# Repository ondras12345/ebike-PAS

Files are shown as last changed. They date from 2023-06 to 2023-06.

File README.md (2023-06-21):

# e-bike PAS signal generator
Eunorau Sin-wave LD-FXK-038 e-bike controller is often used on electric kick
scooters, but those don't have pedals, so you cannot make use of the pedal
assist (PAS) feature. This simple device generates a valid pedalling signal to
achieve cruise control-like functionality.

## Usage
Hold the start button for at least 2 seconds to enable PAS. Start braking to
turn it off.

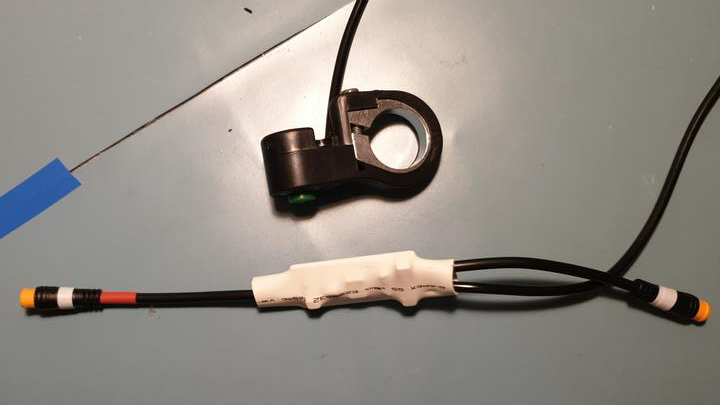
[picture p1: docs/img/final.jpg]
PCBA with connectors attached, wrapped in heatshrink

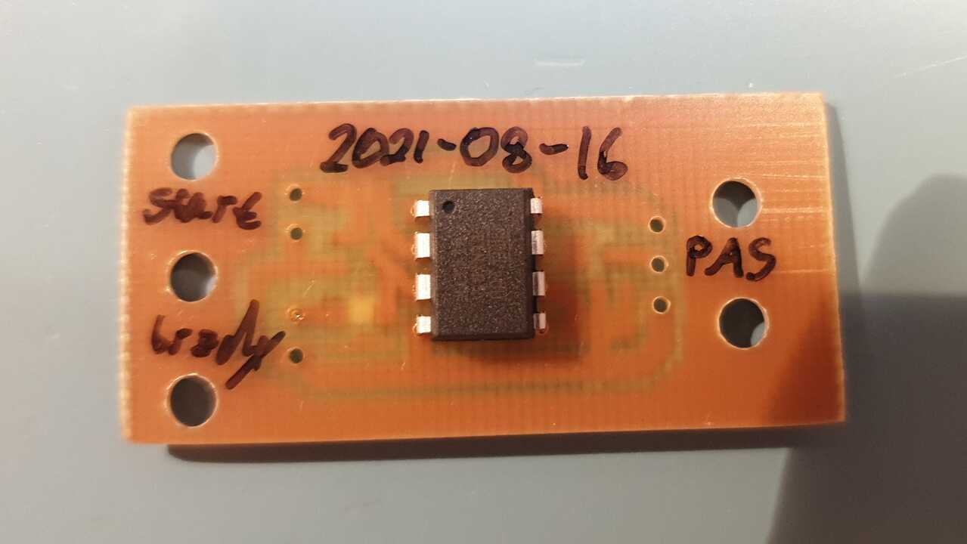
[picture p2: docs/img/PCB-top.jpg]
Top side of the PCBA

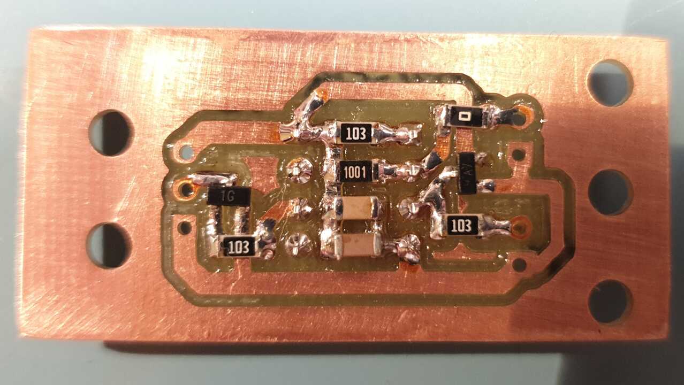
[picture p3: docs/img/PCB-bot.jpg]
Bottom side of the PCBA


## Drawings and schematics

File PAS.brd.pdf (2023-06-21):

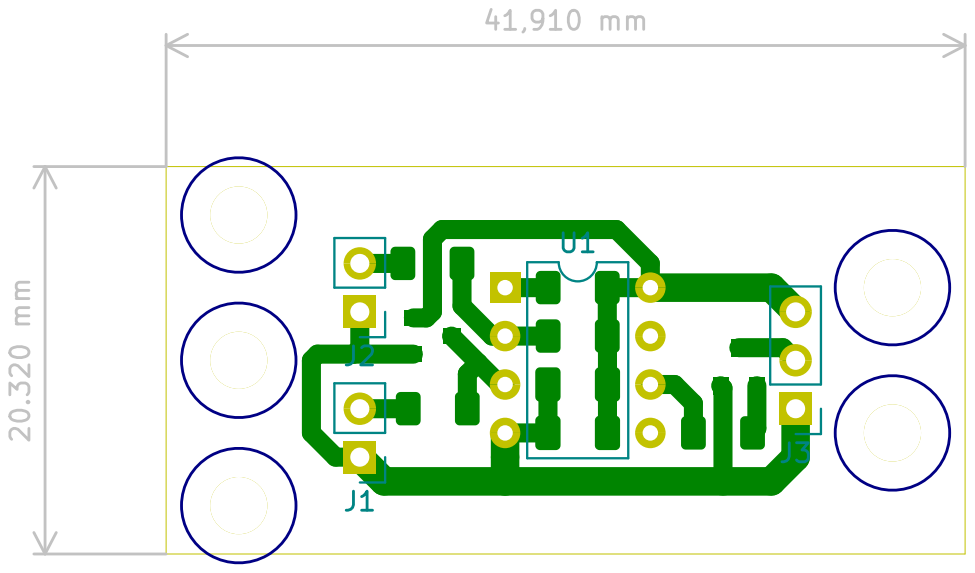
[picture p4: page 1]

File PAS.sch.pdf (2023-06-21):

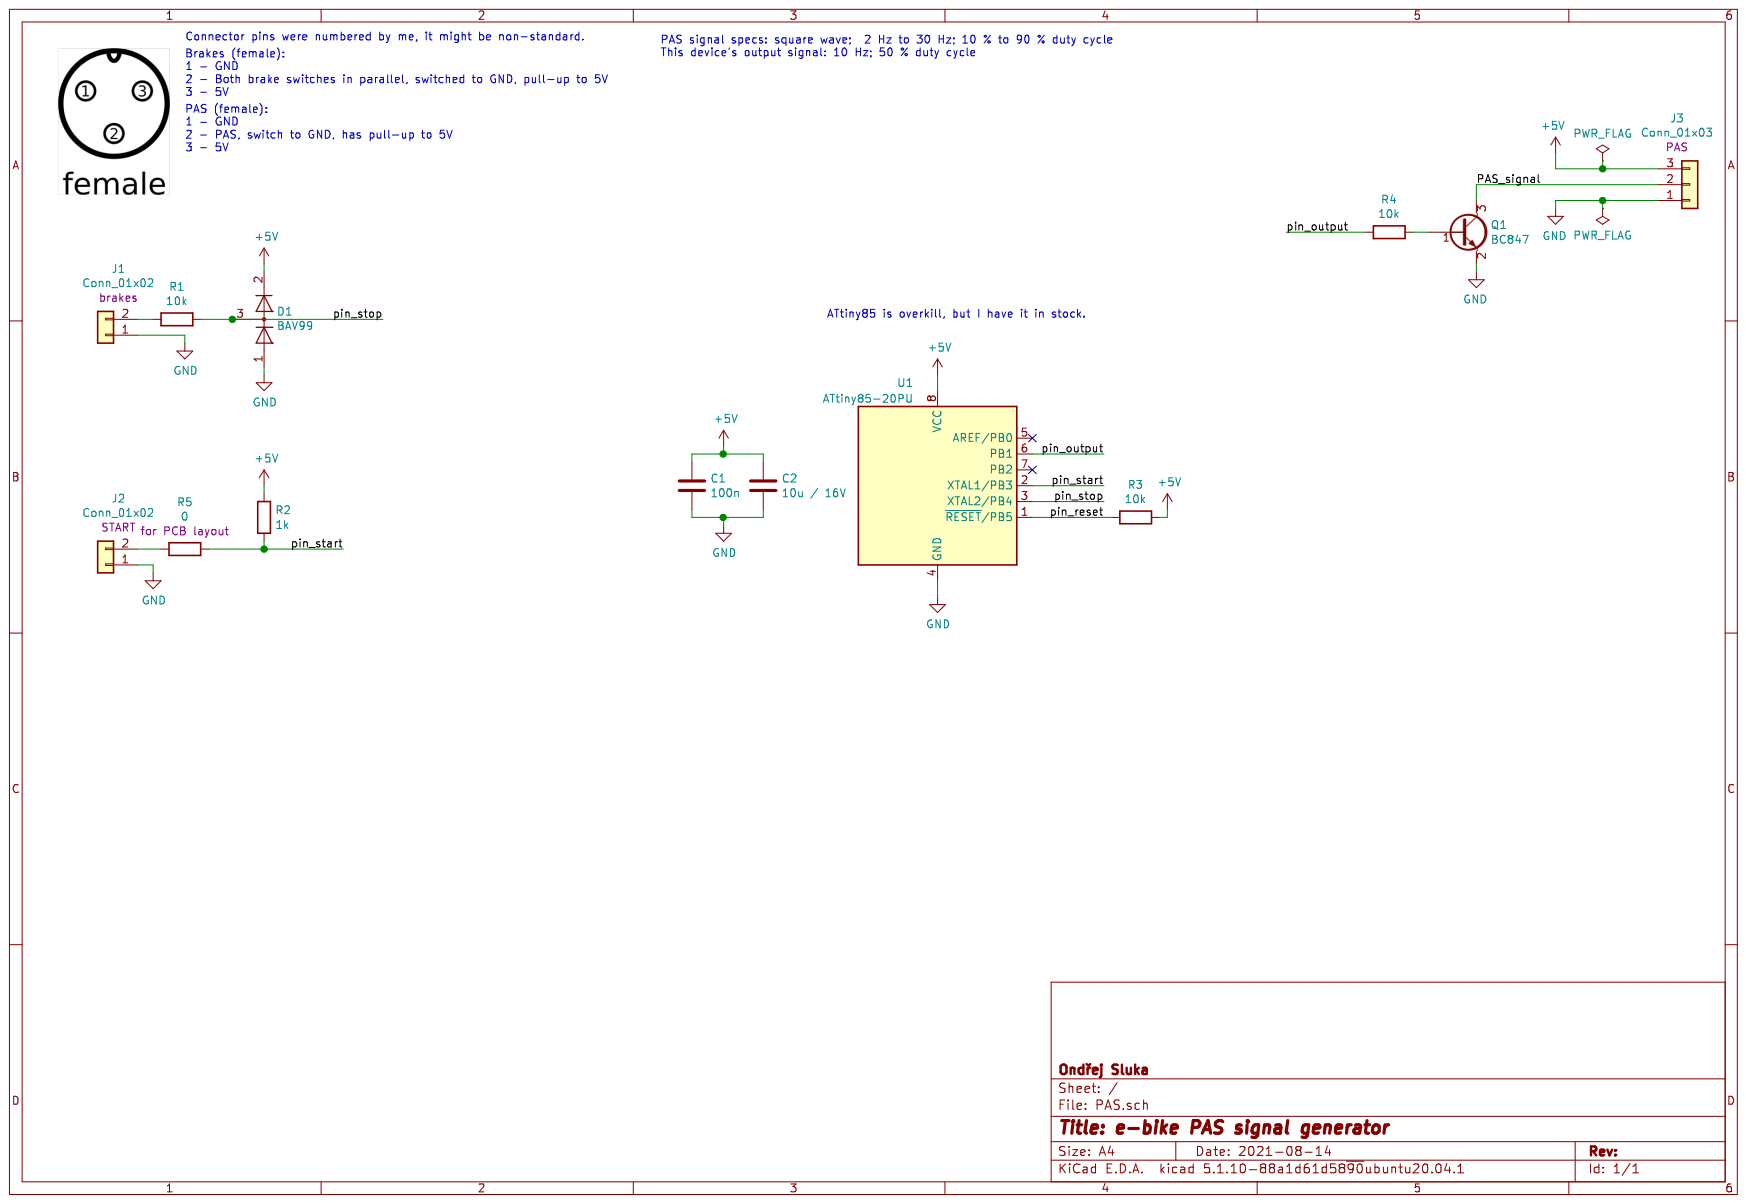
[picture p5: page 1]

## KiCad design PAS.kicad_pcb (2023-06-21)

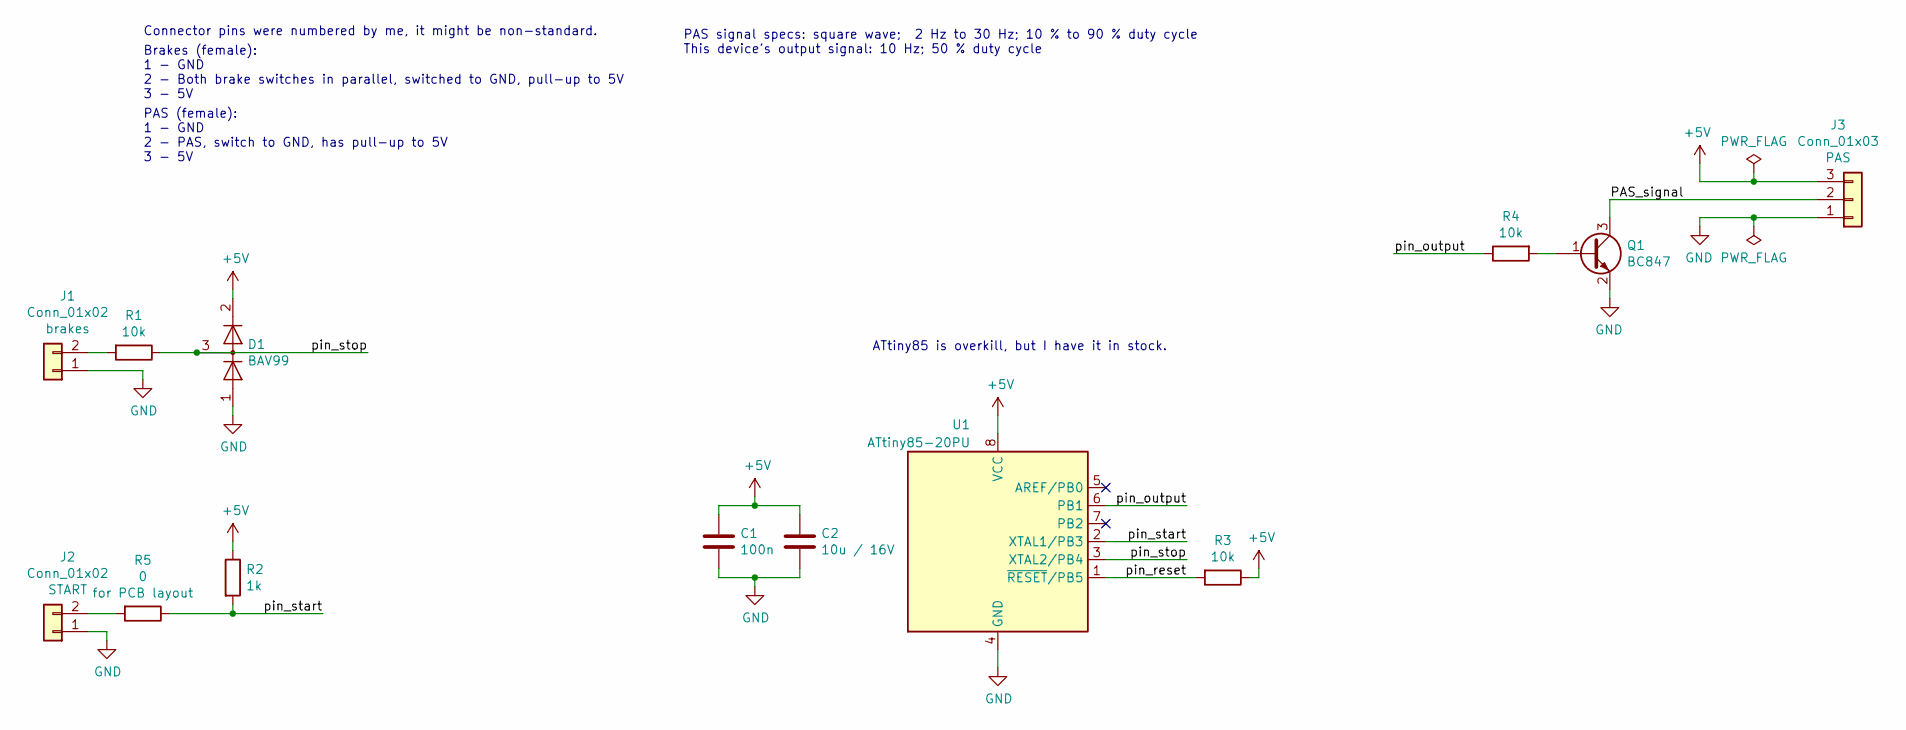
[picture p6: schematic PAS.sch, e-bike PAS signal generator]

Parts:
C1: 100n; C_1206_3216Metric_Pad1.33x1.80mm_HandSolder
C2: 10u / 16V; C_1206_3216Metric_Pad1.33x1.80mm_HandSolder
D1: BAV99; SOT-23
J1, J2: Conn_01x02; PinHeader_1x02_P2.54mm_Vertical
J3: Conn_01x03; PinHeader_1x03_P2.54mm_Vertical
Q1: BC847; SOT-23
R1, R3, R4: 10k; R_1206_3216Metric_Pad1.30x1.75mm_HandSolder
R2: 1k; R_1206_3216Metric_Pad1.30x1.75mm_HandSolder
R5: 0; R_1206_3216Metric_Pad1.30x1.75mm_HandSolder
U1: ATtiny85-20PU; DIP-8_W7.62mm

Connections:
+5V: C1.1, C2.1, D1.2 (A), J3.3, R2.1, R3.1, U1.8 (VCC)
/PAS_signal: J3.2, Q1.3 (C)
/pin_output: R4.1, U1.6 (PB1)
/pin_reset: R3.2, U1.1 (~RESET~/PB5)
/pin_start: R2.2, R5.1, U1.2 (XTAL1/PB3)
/pin_stop: D1.3 (K), R1.1, U1.3 (XTAL2/PB4)
GND: C1.2, C2.2, D1.1 (K), J1.1, J2.1, J3.1, Q1.2 (E), U1.4 (GND)
unnamed: J1.2, R1.2
unnamed: J2.2, R5.2
unnamed: Q1.1 (B), R4.2

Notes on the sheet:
Brakes (female): 1 - GND 2 - Both brake switches in parallel, switched to GND, pull-up to 5V 3 - 5V
Connector pins were numbered by me, it might be non-standard.
PAS (female): 1 - GND 2 - PAS, switch to GND, has pull-up to 5V 3 - 5V
PAS signal specs: square wave; 2 Hz to 30 Hz; 10 % to 90 % duty cycle This device's output signal: 10 Hz; 50 % duty cycle
ATtiny85 is overkill, but I have it in stock.

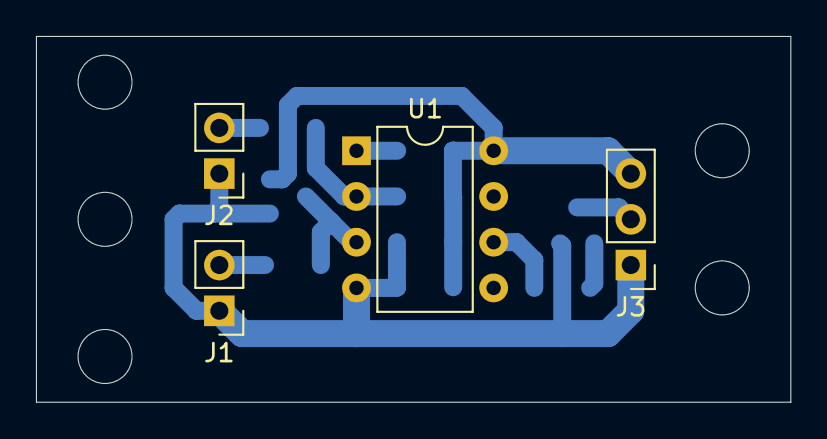
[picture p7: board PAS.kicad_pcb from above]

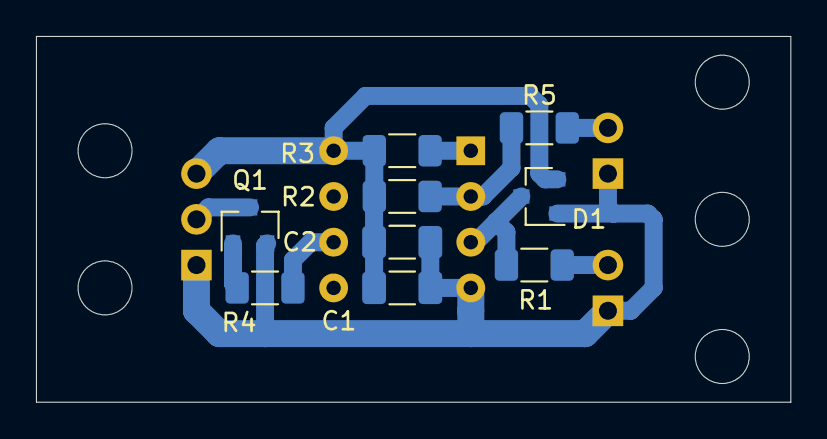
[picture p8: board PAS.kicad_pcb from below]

Board: 2 copper layers, 41.9 x 20.3 mm, 13 parts (9 on the bottom side), 10 nets.

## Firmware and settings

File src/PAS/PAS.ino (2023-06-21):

/*
ATtiny core:
- http://drazzy.com/package_drazzy.com_index.json
- https://github.com/SpenceKonde/ATTinyCore
Board: ATtiny25/45/85 (no bootloader)
Chip: ATtiny85
Clock Source: 1MHz (internal)
Timer1 Clock: CPU (CPU frequency)
LTO: Enabled
millis()/micros(): Enabled
Save EEPROM: EEPROM Retained
B.O.D. Level: B.O.D. Enabled (4.3V)

Burn Bootloader first to set fuses, than Upload Using Programmer.
*/

// https://github.com/PaulStoffregen/TimerOne
// you need to get it from Git (commit
// 756a4b3cf4bd77c8f53483ede2ea0e245409c624 needs to be applied)
#include <TimerOne.h>

#define pin_start 3  // active low
#define pin_stop 4  // active low
#define pin_output 1

#define start_hold_time 2000  // ms
// 10Hz --> 0.1s:
#define output_period 100000  // us


bool running = false;
unsigned long start_prev_millis = 0;
bool prev_pin_start = true;  // active low


void setup()
{
    pinMode(pin_start, INPUT);
    pinMode(pin_stop, INPUT);
    pinMode(pin_output, OUTPUT);

    /* If the start button is held at the time of startup, wait for it to be
    released (in case it was shorted or something). */
    delay(500);
    while(!digitalRead(pin_start));

    Timer1.initialize(output_period / 2);
    Timer1.attachInterrupt(timer1_interrupt);
    Timer1.stop();
    digitalWrite(pin_output, LOW);
}


void loop()
{
    if (!digitalRead(pin_stop) && running)
    {
        running = false;
        Timer1.stop();
        digitalWrite(pin_output, LOW);
    }


    if (running) return;

    // Treat pin_start as HIGH (not pressed) if pin_stop is LOW
    bool curr_pin_start = digitalRead(pin_start) || !digitalRead(pin_stop);

    if (!curr_pin_start && prev_pin_start)
        start_prev_millis = millis();

    if (!curr_pin_start && (millis() - start_prev_millis) >= start_hold_time)
    {
        running = true;
        Timer1.start();
    }

    prev_pin_start = curr_pin_start;
}


void timer1_interrupt()
{
    static bool output_state = false;
    output_state = !output_state;
    digitalWrite(pin_output, output_state);
}
